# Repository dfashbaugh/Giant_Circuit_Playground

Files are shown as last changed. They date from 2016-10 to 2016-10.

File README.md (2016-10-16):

# Giant Circuit Playground

This project contains all of the firmware and software necessary to make a giant circuit playground.

-----------------------------------------------------------

## Setup

### Actual Circuit Playground Firmware

The circuit playground firmware is in the "CircuitPlayGround2Ft" folder. 

Treat this as any other .ino file, and just flash it to the Actual Circuit Playground

### Teensy Firmware

The Teensy firmware is in the "TestEthern" folder. 

To flash the teensy, you will need to install Teensyduino into Arduino. The firmware should compile after Teensyduino has been setup.

After the firmware has been compiled, press the reset button on the Teensy to flash it.

### Raspberry Pi Python Script

The Raspberry Pi python scripts are in the "RaspPiPythonScripts" folder.

If this is a new setup, you will need to open the file TestNeoPixelMatrix.py and follow these steps:
* Scroll down to line 12 and set the SystemType variable as follows
 * SystemType = 0 for the 4 foot playground
 * SystemType = 1 for the 2 foot playground
* Test that running TestNeoPixelMatrix.py works.
* If it works, then we need to set this up to be called on reboot.
 * Find the path to the TestNeoPixelMatrix.py file
 * Edit /etc/rc.local as root
 * Write "sudo /usr/bin/python \<path from first step\> &" on the last line of the file
 * Save the file and reboot!
 
---------------------------------------
 
## Modes
 
### Attract Mode
 
Shows a series of animations, bright colors, and the DigiKey logo. Designed to grab attention from far away
 
### VJ Mode
 
Uses Accelerometers to spin a rainbow. Players can experiment with making the rainbow move faster, slower, reverse direction, and stop!
 
### Simon Mode
 
Play Simon! Hopefully we can call it "Simon" legally.

### Audio Reactive Mode
 
The circuit playground acts as a giant VU meter!

------------------------------------------------

## Troubleshooting

### My Circuit Playground won't respond to button presses!

Reset the circuit playground. 

The Circuit Playground library continuously auto calibrates its capacitive touch which can cause it to be unresponsive if left for long periods of time.
Resetting the system will make it responsive again.

### Circuit playground will not light up on boot

Plug the circuit playground into the Raspberry Pi and reboot the system.

This is a known bug. The python code will not start if a circuit playground is not plugged into the Raspberry Pi on startup.

------------------------------------------------

## Wiring

### 2ft CP

Raspberry Pi 3 connects over Ethernet to a [Teensy 3.2](https://www.pjrc.com/store/teensy32.html) with [Ethernet Shield](https://www.pjrc.com/store/wiz820_sd_adaptor.html)/[WIZ820IO](http://www.digikey.com/product-detail/en/wiznet/WIZ820IO/1278-1015-ND/3829655) and an [OCTOWS shield](https://www.pjrc.com/store/octo28_adaptor.html).

The [Adafruit 8x8 matrices](https://www.adafruit.com/products/1487) are connected clockwise from the top right Matrix to output 1. 1-6 are in order, output 7 connects to matrix 7 & 8, output 8 connects to matrix 9 & 10.

### 4ft CP
Raspberry Pi 3 with a LED [matrix shield](https://github.com/hzeller/rpi-rgb-led-matrix/tree/master/adapter/active-3) from [OSHpark](https://oshpark.com/shared_projects/bFtff2GR). Matrices are connected in line clockwise beginning with the top right matrix with 16 pin IDC cables.

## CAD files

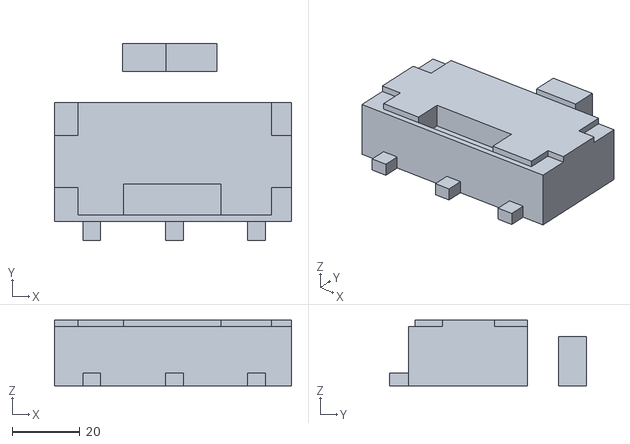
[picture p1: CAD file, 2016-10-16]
STLs/2ft_switch.stl
69.8 x 58.1 x 19.4

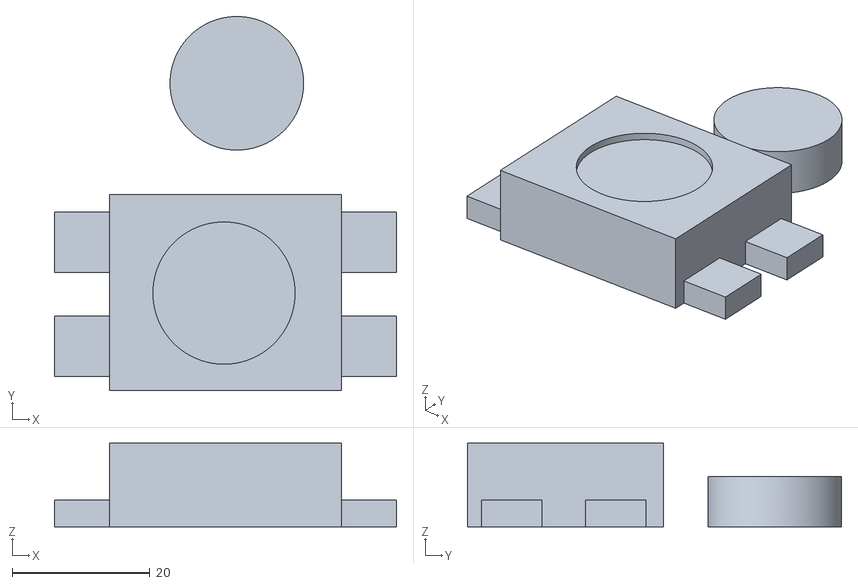
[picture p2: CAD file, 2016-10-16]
STLs/2ft_mini_button.stl
49.6 x 54.2 x 12.1

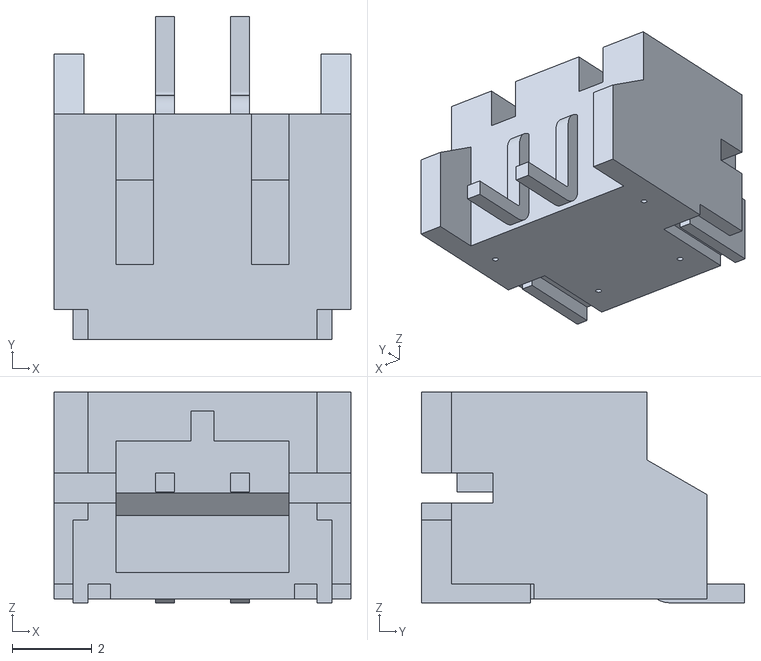
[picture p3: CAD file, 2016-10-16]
STLs/4ft_jst.stl
7.46 x 8.13 x 5.29

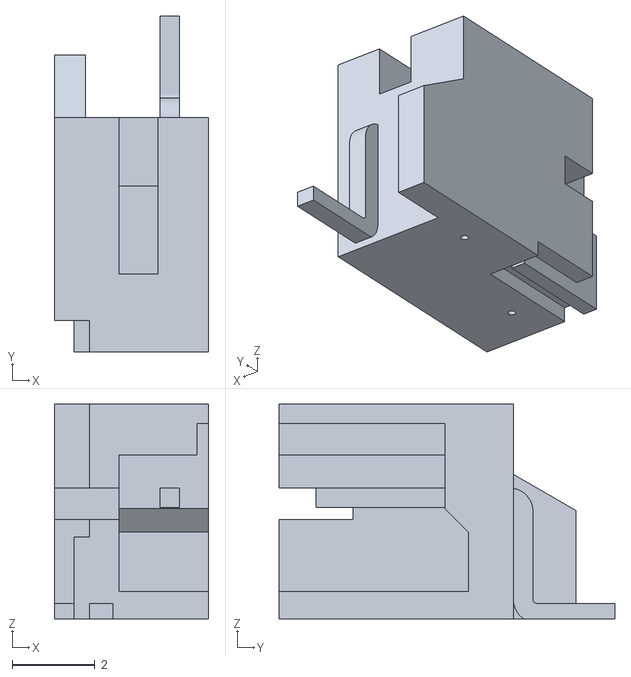
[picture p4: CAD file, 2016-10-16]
STLs/4ft_jst_R.stl
3.73 x 8.13 x 5.20

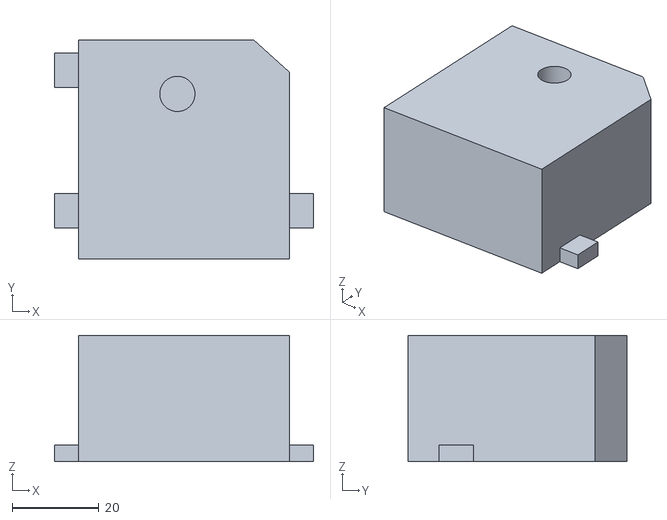
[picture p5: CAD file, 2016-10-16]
STLs/2ft_speaker.stl
59.6 x 50.4 x 29.1

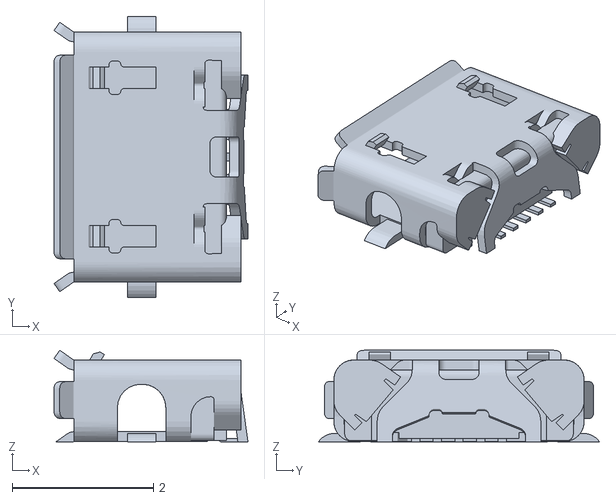
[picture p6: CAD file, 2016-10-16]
STLs/2ft_usb.stl
2.75 x 3.98 x 1.30

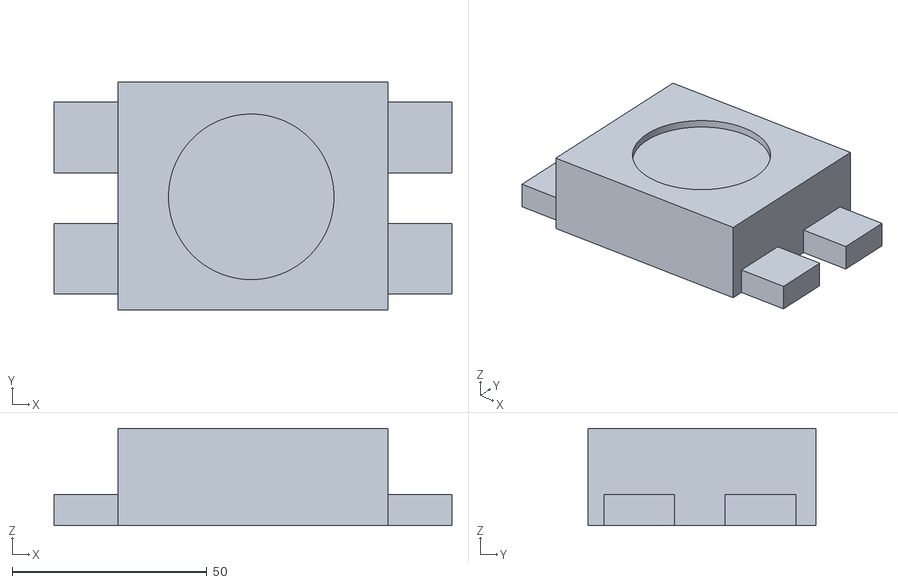
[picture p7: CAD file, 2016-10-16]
STLs/4ft_button_mini.stl
102.2 x 58.7 x 25.0

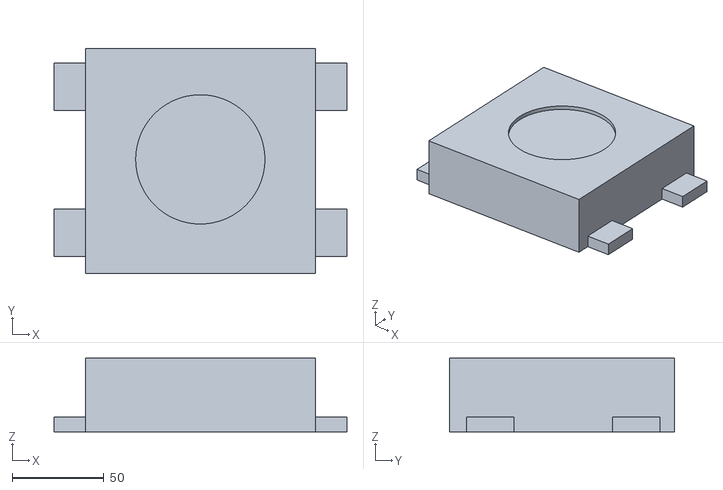
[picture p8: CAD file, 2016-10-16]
STLs/4ft_button.stl
159.4 x 122.5 x 40.0

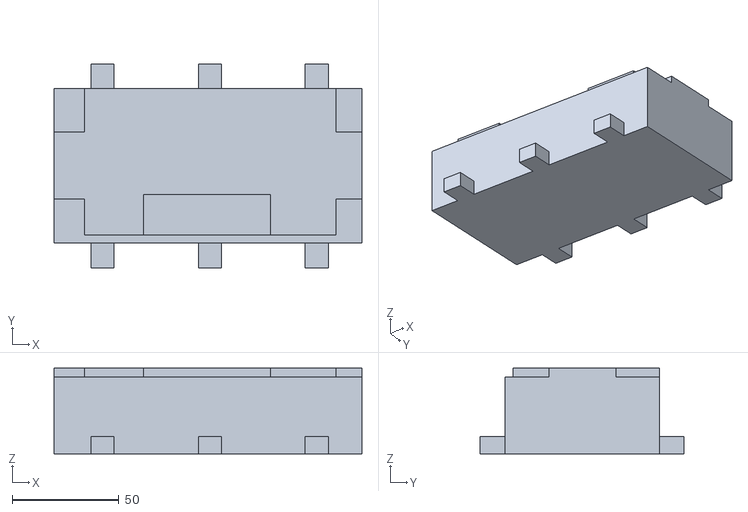
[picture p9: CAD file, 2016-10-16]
STLs/4ft_slide.stl
144.0 x 95.5 x 40.0

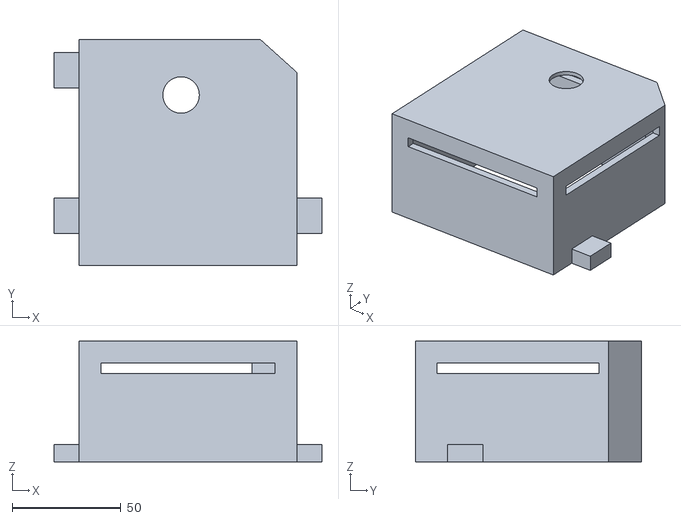
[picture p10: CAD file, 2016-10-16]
STLs/4ft_speaker.stl
123.0 x 103.9 x 55.5

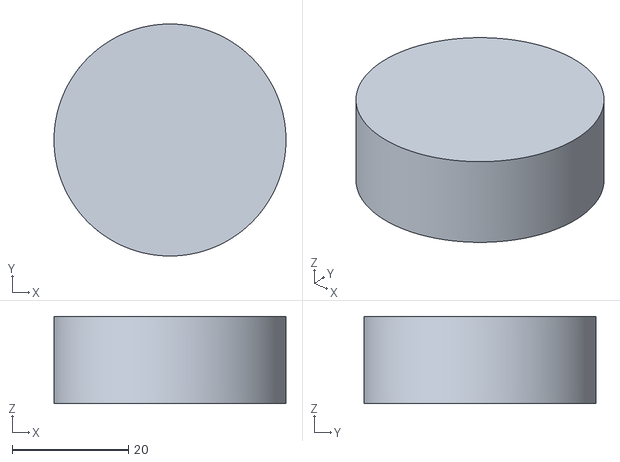
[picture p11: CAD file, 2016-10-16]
STLs/2ft_button_mini_dimple.stl
39.9 x 39.9 x 15.0

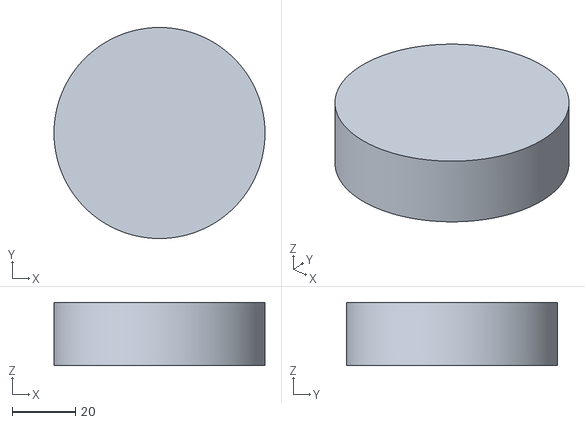
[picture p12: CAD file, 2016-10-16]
STLs/4ft_button_dimple.stl
66.8 x 66.8 x 20.0

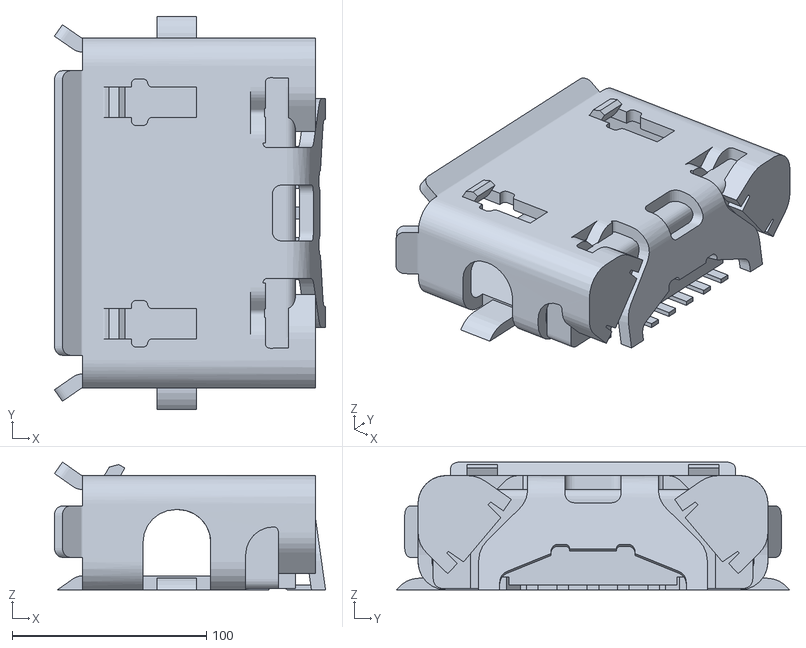
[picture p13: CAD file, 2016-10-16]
STLs/4ft_usb.stl
139.5 x 202.2 x 65.8

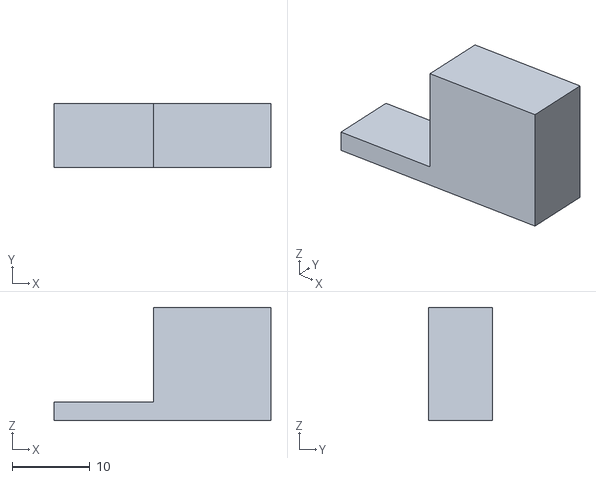
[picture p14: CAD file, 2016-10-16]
STLs/2ft_slide_nub.stl
27.8 x 8.26 x 14.5

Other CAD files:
STLs/2ft jst.stl
STLs/4ft_jst_L.stl
STLs/2ft_button.stl
STLs/4ft_slide_nub.stl
STLs/2ft_jst.stl
STLs/4ft_button_mini_dimple.stl

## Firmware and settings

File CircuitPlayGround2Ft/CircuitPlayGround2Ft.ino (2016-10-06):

#include <Adafruit_CircuitPlayground.h>

boolean playedSoundRed = false;
boolean playedSoundBlue = false;
boolean playedSoundYellow = false;
boolean playedSoundGreen = false;

float X, Y, Z, temp;
int light, sound;

int cap_3, cap_2; //Top left
int cap_1, cap_0; //Bot left
int cap_9, cap_10; //Top right
int cap_6, cap_12; //Bot right

int mode = 2;
int cyclesUntilPush = 2;
int curCycles = 0;

bool slideSwitch, L_button, R_button;

int soundList [1000];
int soundCounter = 0;

int lastRead = 0;

int animationFrame = 0;

String delim = "\t";

#define MIC_PIN         A4  // Microphone is attached to this analog pin (A4 for circuit playground)
#define SAMPLE_WINDOW   10  // Sample window for average level
#define PEAK_HANG       24  // Time of pause before peak dot falls
#define PEAK_FALL        4  // Rate of falling peak dot
#define INPUT_FLOOR     10  // Lower range of analogRead input
#define INPUT_CEILING  500  // Max range of analogRead 


float fscale( float originalMin, float originalMax, float newBegin, float
newEnd, float inputValue, float curve){

  float OriginalRange = 0;
  float NewRange = 0;
  float zeroRefCurVal = 0;
  float normalizedCurVal = 0;
  float rangedValue = 0;
  boolean invFlag = 0;


  // condition curve parameter
  // limit range

  if (curve > 10) curve = 10;
  if (curve < -10) curve = -10;

  curve = (curve * -.1) ; // - invert and scale - this seems more intuitive - postive numbers give more weight to high end on output 
  curve = pow(10, curve); // convert linear scale into lograthimic exponent for other pow function

  /*
   Serial.println(curve * 100, DEC);   // multply by 100 to preserve resolution  
   Serial.println(); 
   */

  // Check for out of range inputValues
  if (inputValue < originalMin) {
    inputValue = originalMin;
  }
  if (inputValue > originalMax) {
    inputValue = originalMax;
  }

  // Zero Refference the values
  OriginalRange = originalMax - originalMin;

  if (newEnd > newBegin){ 
    NewRange = newEnd - newBegin;
  }
  else
  {
    NewRange = newBegin - newEnd; 
    invFlag = 1;
  }

  zeroRefCurVal = inputValue - originalMin;
  normalizedCurVal  =  zeroRefCurVal / OriginalRange;   // normalize to 0 - 1 float

  // Check for originalMin > originalMax  - the math for all other cases i.e. negative numbers seems to work out fine 
  if (originalMin > originalMax ) {
    return 0;
  }

  if (invFlag == 0){
    rangedValue =  (pow(normalizedCurVal, curve) * NewRange) + newBegin;

  }
  else     // invert the ranges
  {   
    rangedValue =  newBegin - (pow(normalizedCurVal, curve) * NewRange); 
  }

  return rangedValue;
}


void setup() {
  Serial.begin(9600);
  CircuitPlayground.begin();
}

void loop() {

  X = CircuitPlayground.motionX();
  Y = CircuitPlayground.motionY();
  Z = CircuitPlayground.motionZ();
  
  temp = CircuitPlayground.temperature();

  slideSwitch = CircuitPlayground.slideSwitch(); //True if Left, False if Right

  L_button = CircuitPlayground.leftButton(); //0 Unless pressed
  R_button = CircuitPlayground.rightButton();

  curCycles++;
  if(L_button && curCycles > cyclesUntilPush)
  {
    mode--;
    if(mode == -1)
      mode = 3;
    mode = mode%4;
    curCycles = 0;
    if(mode == 0)
      CircuitPlayground.playTone(800, 100);
    else if(mode == 1)
      CircuitPlayground.playTone(1000, 100);
    else if(mode == 2)
      CircuitPlayground.playTone(1200, 100);
    else if(mode == 3)
      CircuitPlayground.playTone(1600, 100);
  }
  else if(R_button && curCycles > cyclesUntilPush)
  {
    mode++;
    mode = mode%4;
    curCycles = 0;
    if(mode == 0)
      CircuitPlayground.playTone(800, 100);
    else if(mode == 1)
      CircuitPlayground.playTone(1000, 100);
    else if(mode == 2)
      CircuitPlayground.playTone(1200, 100);
    else if(mode == 3)
      CircuitPlayground.playTone(1600, 100);
  }


  light = CircuitPlayground.lightSensor();

  cap_2 = CircuitPlayground.readCap(2); 
  cap_3 = CircuitPlayground.readCap(3); 
  cap_0 = CircuitPlayground.readCap(0); 
  cap_1 = CircuitPlayground.readCap(1); 
  cap_9 = CircuitPlayground.readCap(9); 
  cap_10 = CircuitPlayground.readCap(10); 
  cap_6 = CircuitPlayground.readCap(6); 
  cap_12 = CircuitPlayground.readCap(12); 

  if(mode == 1)
  {
    for(int i = 0; i < 10; i++)
    {
      CircuitPlayground.setPixelColor(i, 0,   0,   0);
    }

    int redValue = (cap_2+cap_3);
    if(redValue > 255) 
      redValue = 255;
    if(redValue > 200 && !playedSoundRed)
    {
      CircuitPlayground.playTone(800, 100);
      playedSoundRed = true;
    }
    else if(redValue < 10)
      playedSoundRed = false;
    CircuitPlayground.setPixelColor(0, redValue,   0,   0);
    CircuitPlayground.setPixelColor(1, redValue,   0,   0);
  
    int greenValue = (cap_0+cap_1);
    if(greenValue > 255)
      greenValue = 255;
    if(greenValue > 200 && !playedSoundGreen)
    {
      CircuitPlayground.playTone(800, 100);
      playedSoundGreen = true;
    }
    else if(greenValue < 10)
      playedSoundGreen = false;
    CircuitPlayground.setPixelColor(3, 0,   greenValue,   0);
    CircuitPlayground.setPixelColor(4, 0,   greenValue,   0);
  
    int blueValue = (cap_6+cap_12);
    if(blueValue > 255)
      blueValue = 255;
    if(blueValue > 200 && !playedSoundBlue)
    {
      CircuitPlayground.playTone(800, 100);
      playedSoundBlue = true;
    }
    else if(blueValue < 10)
      playedSoundBlue = false;
    CircuitPlayground.setPixelColor(5, 0,   0,   blueValue);
    CircuitPlayground.setPixelColor(6, 0,   0,   blueValue);
  
    int yellowValue = (cap_9+cap_10);
    if(yellowValue > 255)
      yellowValue = 255;
    if(yellowValue > 200 && !playedSoundYellow)
    {
      CircuitPlayground.playTone(800, 100);
      playedSoundYellow = true;
    }
    else if(yellowValue < 10)
      playedSoundYellow = false;
    CircuitPlayground.setPixelColor(8, yellowValue,   yellowValue,   0);
    CircuitPlayground.setPixelColor(9, yellowValue,   yellowValue,   0);
  }
  else if(mode == 2 || mode == 0)
  {
    int colorValue = 0;
    if(animationFrame > 25)
      colorValue = 255 - (animationFrame*10)%255;
    else
      colorValue = (animationFrame*10)%255;

    for(int i = 0; i < 10; i++)
    {
      CircuitPlayground.setPixelColor(i, colorValue,   colorValue,   colorValue);
    }
  }
  else if(mode == 3)
  {
    for(int i = 0; i < 10; i++)
    {
      CircuitPlayground.setPixelColor(i, 255-sound,   0,   0);
    }
  }

  Serial.print(X);
  Serial.print(delim);

  Serial.print(Y);
  Serial.print(delim);

  Serial.print(Z);
  Serial.print(delim);

  Serial.print(temp);
  Serial.print(delim);

  Serial.print(slideSwitch);
  Serial.print(delim);

  Serial.print(L_button);
  Serial.print(delim);

  Serial.print(R_button);
  Serial.print(delim);

  Serial.print(light);
  Serial.print(delim);

  Serial.print(sound);
  Serial.print(delim);

  Serial.print(cap_2);
  Serial.print(delim);

  Serial.print(cap_3);
  Serial.print(delim);

  Serial.print(cap_0);
  Serial.print(delim);

  Serial.print(cap_1);
  Serial.print(delim);

  Serial.print(cap_9);
  Serial.print(delim);

  Serial.print(cap_10);
  Serial.print(delim);

  Serial.print(cap_6);
  Serial.print(delim);

  Serial.print(cap_12);
  Serial.print(delim);

  Serial.println(mode);

  unsigned int signalMax = 0;
  unsigned int sample = 0;
  unsigned int peakToPeak = 0;
  unsigned int signalMin = 1023;
  unsigned int c, y;
  unsigned long startMillis = millis();

  // collect data for length of sample window (in mS)
  while (millis() - startMillis < 50)
  {
    sample = analogRead(MIC_PIN);
    if (sample < 1024)  // toss out spurious readings
    {
      if (sample > signalMax)
      {
        signalMax = sample;  // save just the max levels
      }
      else if (sample < signalMin)
      {
        signalMin = sample;  // save just the min levels
      }
    }
  }
  peakToPeak = signalMax - signalMin;  // max - min = peak-peak amplitude

  //Scale the input logarithmically instead of linearly
  sound = fscale(INPUT_FLOOR, INPUT_CEILING, 100, 0, peakToPeak, 2);
  sound = map(sound, 0,100, 0, 255);

  animationFrame++;
  if(animationFrame > 50)
    animationFrame = 0;

}

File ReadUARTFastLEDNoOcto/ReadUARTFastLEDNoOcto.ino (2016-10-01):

#include <FastLED.h>

#define NUM_LEDS 640
#define MEMORY_SIZE NUM_LEDS*3

byte drawingMemory[MEMORY_SIZE];

CRGB leds1[64];
CRGB leds2[64];
CRGB leds3[64];
CRGB leds4[64];
CRGB leds5[64];
CRGB leds6[64];
CRGB leds7[128];
CRGB leds8[128];

long memoryCounter = 0;

int recvState = 0;
void CheckForDelimeter(byte recvInfo)
{
	if(recvInfo == 's' && recvState == 0)
		recvState = 1;
	else if(recvInfo == 't' && recvState == 1)
		recvState = 2;
	else if(recvInfo == 'a' && recvState == 2)
		recvState = 3;
	else if(recvInfo == 'r' && recvState == 3)
		recvState = 4;
	else if(recvInfo == 't' && recvState == 4)
	{
		recvState = 0;
		memoryCounter = 0;
	}
	else
		recvState = 0;
}

void setup()
{
	Serial.begin(500000);
	FastLED.addLeds<WS2812B, 2,  GRB>(leds1, 64);
    FastLED.addLeds<WS2812B, 14, GRB>(leds2, 64);
    FastLED.addLeds<WS2812B, 7,  GRB>(leds3, 64);
    FastLED.addLeds<WS2812B, 8,  GRB>(leds4, 64);
    FastLED.addLeds<WS2812B, 6,  GRB>(leds5, 64);
    FastLED.addLeds<WS2812B, 20, GRB>(leds6, 64);
    FastLED.addLeds<WS2812B,  21, GRB>(leds7, 128);
    FastLED.addLeds<WS2812B,  5, GRB>(leds8, 128);
   	FastLED.show();
}

long lastMillis = 0;

void loop ()
{
	if(Serial.available())
	{
		byte recvInfo = Serial.read();

		if(memoryCounter < MEMORY_SIZE)
		{
			recvInfo = map(recvInfo, 0, 255, 0, 128);
			drawingMemory[memoryCounter] = recvInfo;
			memoryCounter++;
		}

		CheckForDelimeter(recvInfo);
	}

	if(memoryCounter == MEMORY_SIZE)
	{
		//correctDrawingMemory();

         //for(int i = 0; i < NUM_LEDS; i++ )
         //{
         //	CRGB myColor;
         //	myColor.green = trueDrawingMemory[i*3];
         //	myColor.red = trueDrawingMemory[i*3+1];
         //	myColor.blue = trueDrawingMemory[i*3+2];
         // 	leds[i] = myColor;
         //}

		for(int i = 0; i < NUM_LEDS; i++)
		{
			CRGB myColor;
			myColor.green = drawingMemory[i*3];
			myColor.red = drawingMemory[i*3+1];
			myColor.blue = drawingMemory[i*3+2];

			if(i < 64) // Strip 1
				leds1[i] = myColor;
			else if(i < 128) // Strip 2
				leds2[i%64] = myColor;
			else if(i < 192) // Strip 3
				leds3[i%64] = myColor;
			else if(i < 256) // Strip 4
				leds4[i%64] = myColor;
			else if(i < 320) // Strip 5
				leds5[i%64] = myColor;
			else if(i < 384) // Strip 6
				leds6[i%64] = myColor;
			else if(i < 512) // Strip 7
				leds7[i%128] = myColor;
			else if(i < 640) // Strip 8
				leds8[i%128] = myColor;
		}

         FastLED.show();
	}
}

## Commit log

2016-09-26 Added circuit playground send all code
2016-09-26 NEED TO REORGANIZE CODE... But the Circuit Playground talks to the Neopixels
2016-09-26 Made LED Drawing safer
2016-09-27 Fixed pixel positioning for Neo Pixels
    [NeoPixelMatrix.py, TestNeoPixelMatrix.py]
2016-09-27 Throttled circuit playground connection and added RGB Matrix test
2016-09-28 Changed Baud Rate to 500000 to be able to get high frame rates
2016-09-28 Set Circuit Playground Frame Rate to 30FPS
2016-09-28 Made cross matrix compatible and fixed a spelling error
    [TestNeoPixelMatrix.py]
2016-09-28 Added drawing memory corrector
    [ReadUARTTeensyNeoPixelHardwareSerial.ino]
2016-09-29 Added lights and sounds to circuit playground
2016-09-29 Added a switch for the various matrix and playground types
2016-09-29 Put frame counter in a universal position
2016-09-29 Adapted new serial drawing code to Raspberry Pi
2016-09-29 Added end delimiter to the Teensy UART Serial
2016-09-29 Added default raspberry pi serial ports
2016-09-29 Massively lowered the frame rate on the neo pixels
2016-09-30 Set framerate to 20FPS
2016-09-30 Made 4 ft circuit playground updated
2016-09-30 Fixed audio reactive for 2 Foot Circuit Playground
    [CircuitPlayGround2Ft.ino]
2016-09-30 Added mode relative animations to the circuit playground
2016-09-30 Updated 2 foot circuit playground code
2016-10-01 Fixed rainbow image sound reactive
    [TestNeoPixelMatrix.py]
2016-10-04 Made minor improvements to python and circuit playground code
2016-10-06 Made Circuit playground able to be unplugged during operation. And Made circuit playground animate faster
2016-10-06 Made animations continue after failure
    [CircuitPlayGround.py]
2016-10-06 Replaced part of attract mode with a rainbow
    [TestNeoPixelMatrix.py]
2016-10-06 Changed Teensy drawing to map to LEDs properly
2016-10-14 Added description explaining to have circuit playground plugged in on boot.
2016-10-16 added STL files for printing
    [2ft jst.stl, 2ft_button.stl, 2ft_button_mini_dimple.stl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]
2016-10-16 added wiring description
